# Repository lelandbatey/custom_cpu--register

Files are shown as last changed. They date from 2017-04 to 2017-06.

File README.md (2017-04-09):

CPU Register
============

This repo contains PCB designs for the second component of Ben Eater's
educational 8-bit CPU, the CPU registers. You can [watch Mr. Eaters *fantastic*
series on designing and building this CPU on his Youtube
channel.](https://www.youtube.com/user/eaterbc/videos)

Each CPU will need three of these registers, one to act as the **instruction**
register, one as the **A** register, and one as the **B** register. The
difference between the A/B registers and the instruction register is that the
four most significant bits of the instruction register won't be directed back
onto the bus, but instead are used as input to the instruction decoder. The
design intentionally incorporates fake resistors in between the LED's and the
LS74245 which may be used as the point where those four most significant bits
are split off towards the instruction decoder.

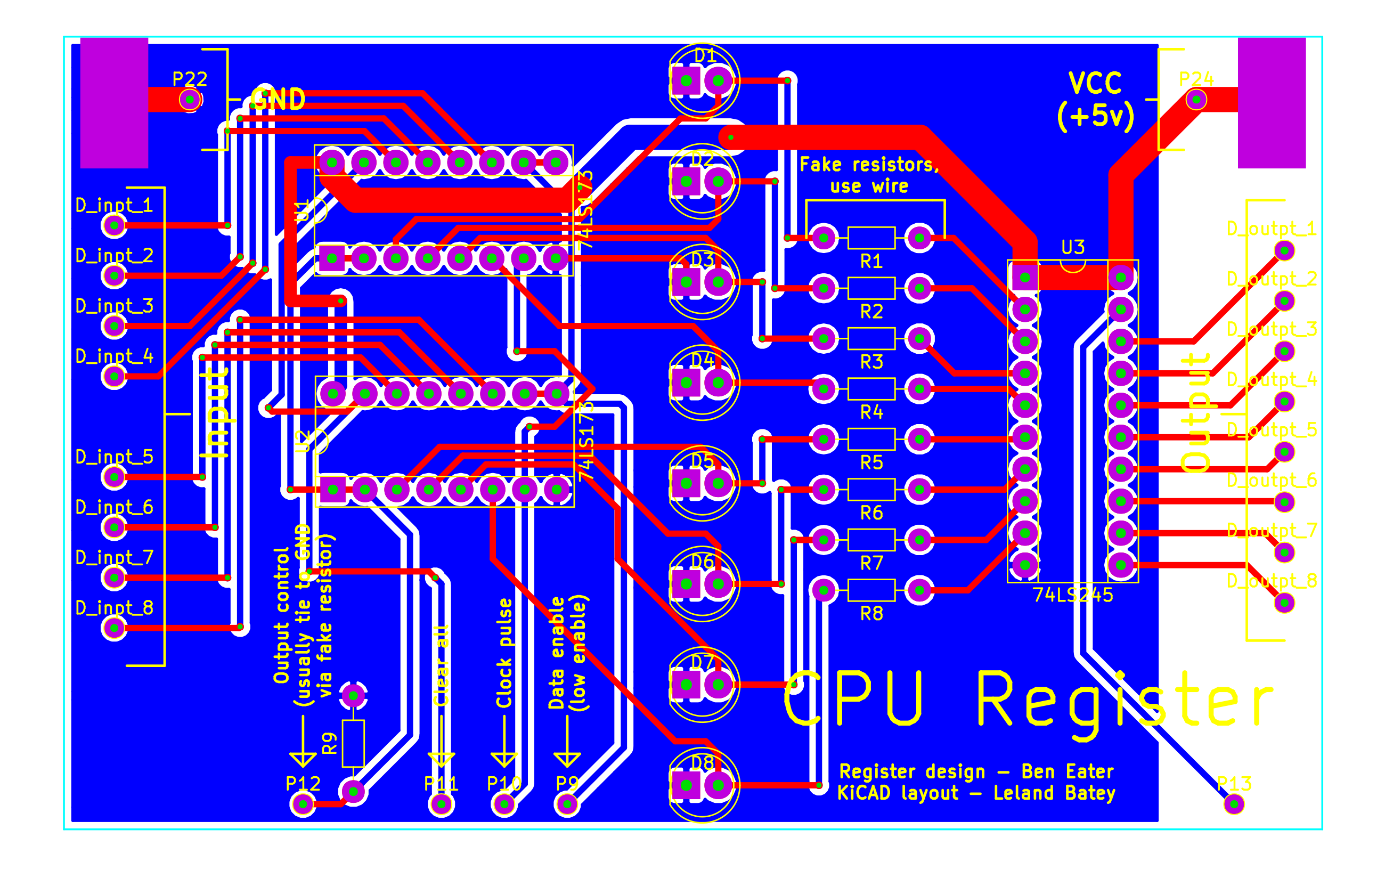
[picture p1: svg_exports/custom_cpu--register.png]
Render of the register PCB


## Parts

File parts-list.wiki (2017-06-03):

= Parts list for register module =

| Part name | Count | Unit Price | Total price |
|---|---|---|---|
| LED (Yellow) | 8 | $0.20 | $1.60 |
| Pin Headers, 1x8 strip | 2 | $0.80 | $1.60 |
| 16 pin IC socket | 2 | $0.18 | $0.36 |
| 20 pin IC socket | 1 | $0.24 | $0.24 |
| 74LS173 (4-bit register) | 2 | $1.35 | $2.70 |
| 74LS245 (bus tranciever) | 1 | $0.87 | $0.87 |
| | | | |

Total:  $7.37

1.6 + 1.6 + 0.36 + 0.24 + 2.7 + 0.87

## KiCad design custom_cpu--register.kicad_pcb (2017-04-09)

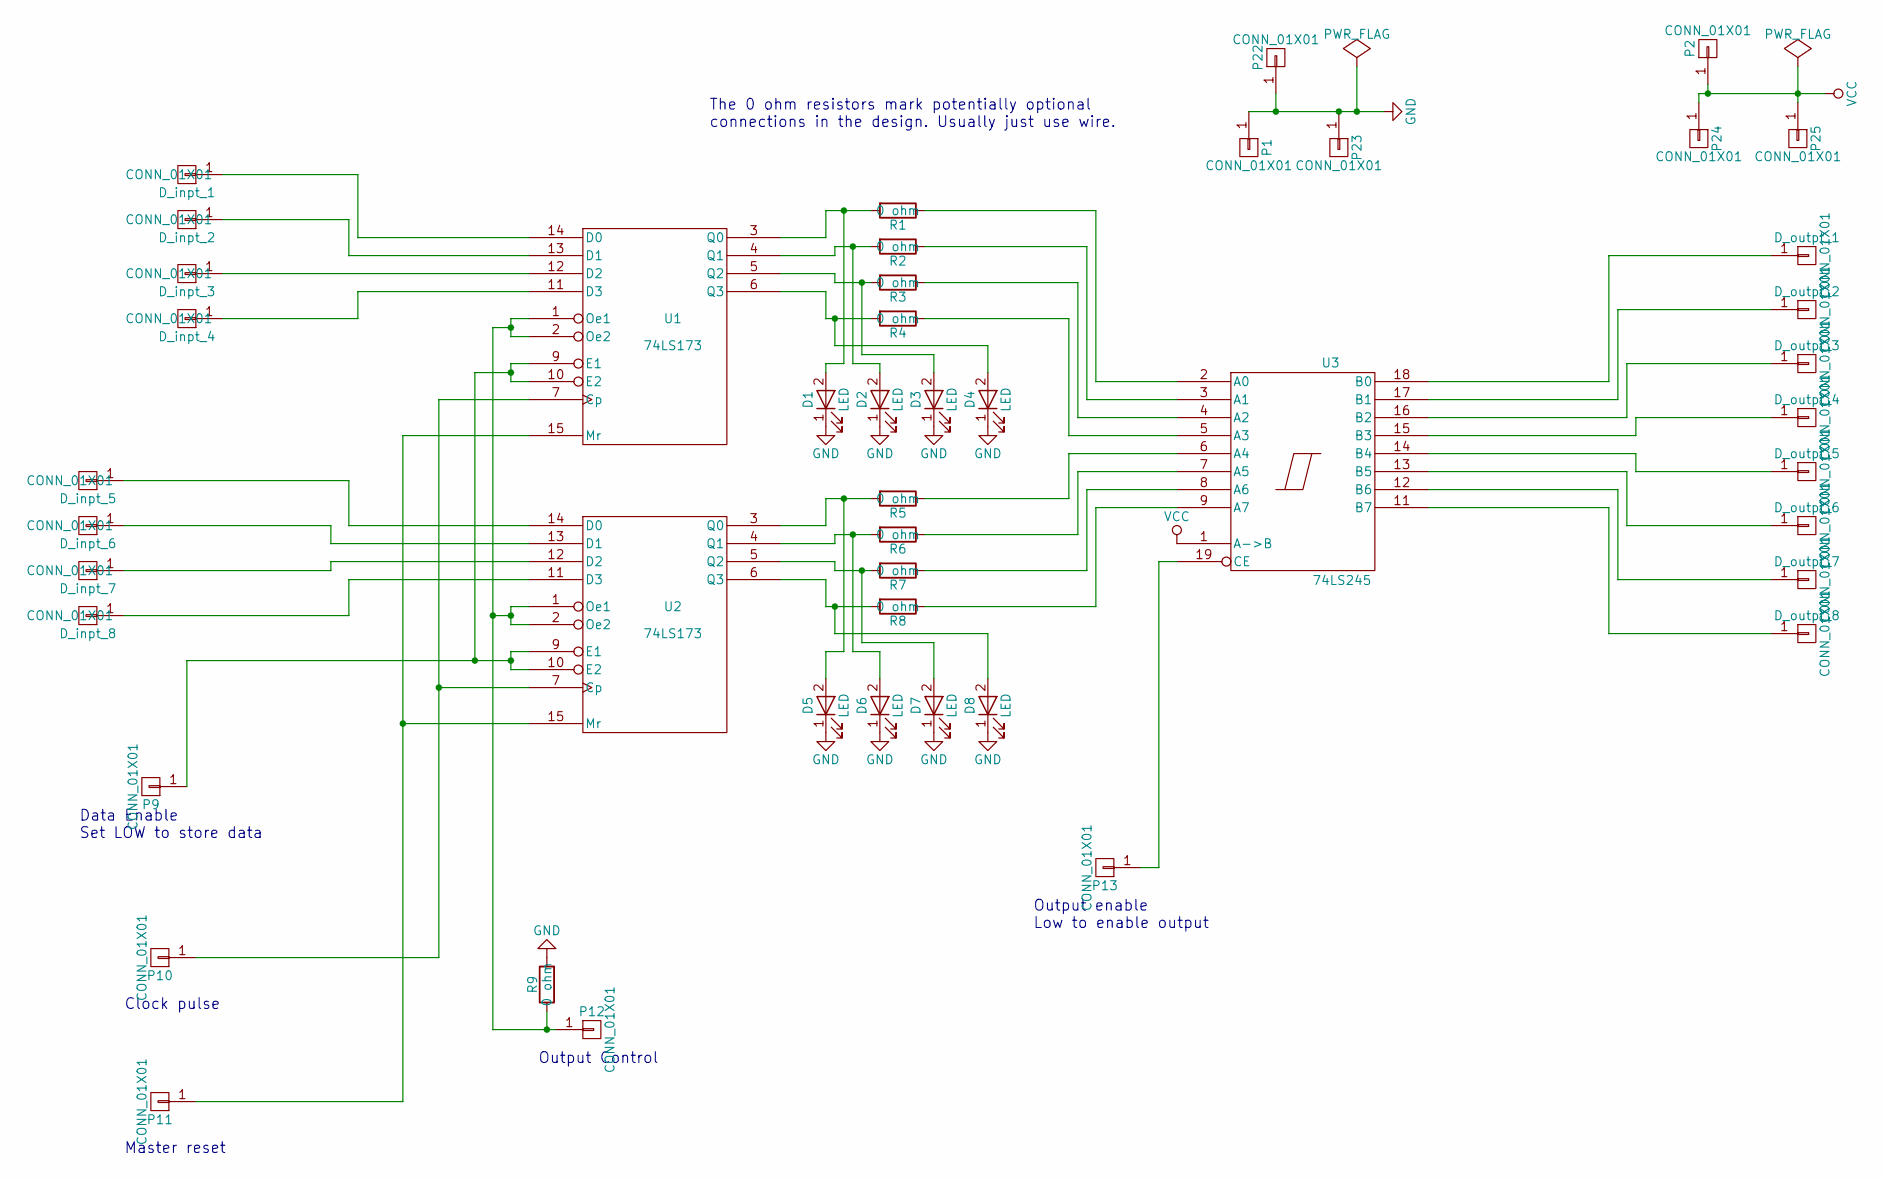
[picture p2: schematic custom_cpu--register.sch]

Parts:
D1, D2, D3, D4, D5, D6, D7, D8: LED; LED_D5.0mm
D_inpt_1, D_inpt_2, D_inpt_3, D_inpt_4, D_inpt_5, D_inpt_6, D_inpt_7, D_inpt_8: CONN_01X01; PINTST
D_outpt_1, D_outpt_2, D_outpt_3, D_outpt_4, D_outpt_5, D_outpt_6, D_outpt_7, D_outpt_8: CONN_01X01; PINTST
P1, P2, P23, P25: CONN_01X01; SolderWirePad_single_SMD_5x10mm
P9, P10, P11, P12, P13, P22, P24: CONN_01X01; PINTST
R1, R2, R3, R4, R5, R6, R7, R8, R9: 0 ohm; R_Axial_DIN0204_L3.6mm_D1.6mm_P7.62mm_Horizontal
U1, U2: 74LS173; DIP-16_W7.62mm_Socket
U3: 74LS245; DIP-20_W7.62mm_Socket

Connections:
GND: D1.1 (K), D2.1 (K), D3.1 (K), D4.1 (K), D5.1 (K), D6.1 (K), D7.1 (K), D8.1 (K), P1.1, P22.1, P23.1, R9.2, U1.8 (GND), U2.8 (GND), U3.10 (GND)
unnamed: D1.2 (A), R1.2, U1.3 (Q0)
unnamed: D2.2 (A), R2.2, U1.4 (Q1)
unnamed: D3.2 (A), R3.2, U1.5 (Q2)
unnamed: D4.2 (A), R4.2, U1.6 (Q3)
unnamed: D5.2 (A), R5.2, U2.3 (Q0)
unnamed: D6.2 (A), R6.2, U2.4 (Q1)
unnamed: D7.2 (A), R7.2, U2.5 (Q2)
unnamed: D8.2 (A), R8.2, U2.6 (Q3)
unnamed: D_inpt_1.1, U1.14 (D0)
unnamed: D_inpt_2.1, U1.13 (D1)
unnamed: D_inpt_3.1, U1.12 (D2)
unnamed: D_inpt_4.1, U1.11 (D3)
unnamed: D_inpt_5.1, U2.14 (D0)
unnamed: D_inpt_6.1, U2.13 (D1)
unnamed: D_inpt_7.1, U2.12 (D2)
unnamed: D_inpt_8.1, U2.11 (D3)
unnamed: D_outpt_1.1, U3.18 (B0)
unnamed: D_outpt_2.1, U3.17 (B1)
unnamed: D_outpt_3.1, U3.16 (B2)
unnamed: D_outpt_4.1, U3.15 (B3)
unnamed: D_outpt_5.1, U3.14 (B4)
unnamed: D_outpt_6.1, U3.13 (B5)
unnamed: D_outpt_7.1, U3.12 (B6)
unnamed: D_outpt_8.1, U3.11 (B7)
unnamed: P9.1, U1.9 (E1), U1.10 (E2), U2.9 (E1), U2.10 (E2)
unnamed: P10.1, U1.7 (Cp), U2.7 (Cp)
unnamed: P11.1, U1.15 (Mr), U2.15 (Mr)
unnamed: P12.1, R9.1, U1.1 (Oe1), U1.2 (Oe2), U2.1 (Oe1), U2.2 (Oe2)
unnamed: P13.1, U3.19 (CE)
unnamed: R1.1, U3.2 (A0)
unnamed: R2.1, U3.3 (A1)
unnamed: R3.1, U3.4 (A2)
unnamed: R4.1, U3.5 (A3)
unnamed: R5.1, U3.6 (A4)
unnamed: R6.1, U3.7 (A5)
unnamed: R7.1, U3.8 (A6)
unnamed: R8.1, U3.9 (A7)
VCC: P2.1, P24.1, P25.1, U1.16 (VCC), U2.16 (VCC), U3.1 (A->B), U3.20 (VCC)

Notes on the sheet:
Data Enable Set LOW to store data
Clock pulse
Master reset
Output Control
Output enable Low to enable output
The 0 ohm resistors mark potentially optional connections in the design. Usually just use wire.

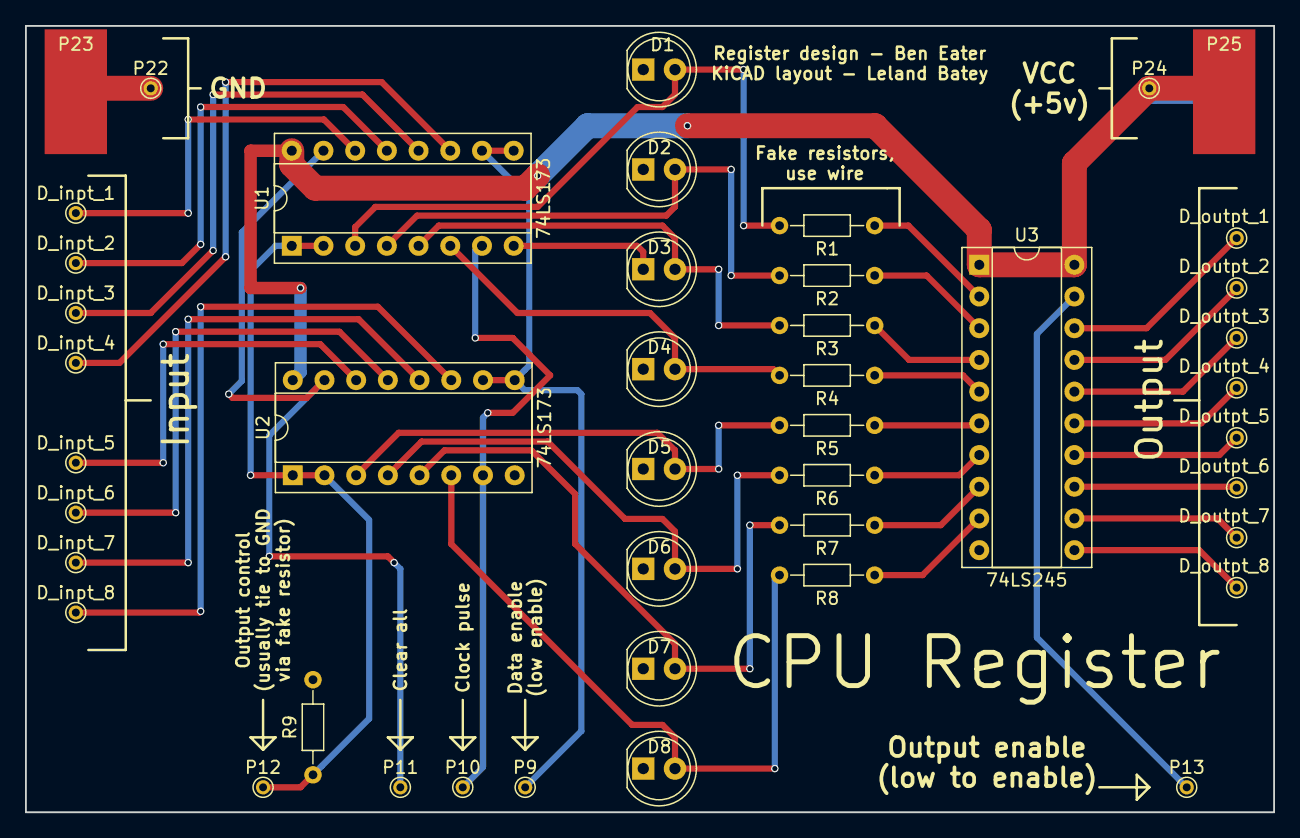
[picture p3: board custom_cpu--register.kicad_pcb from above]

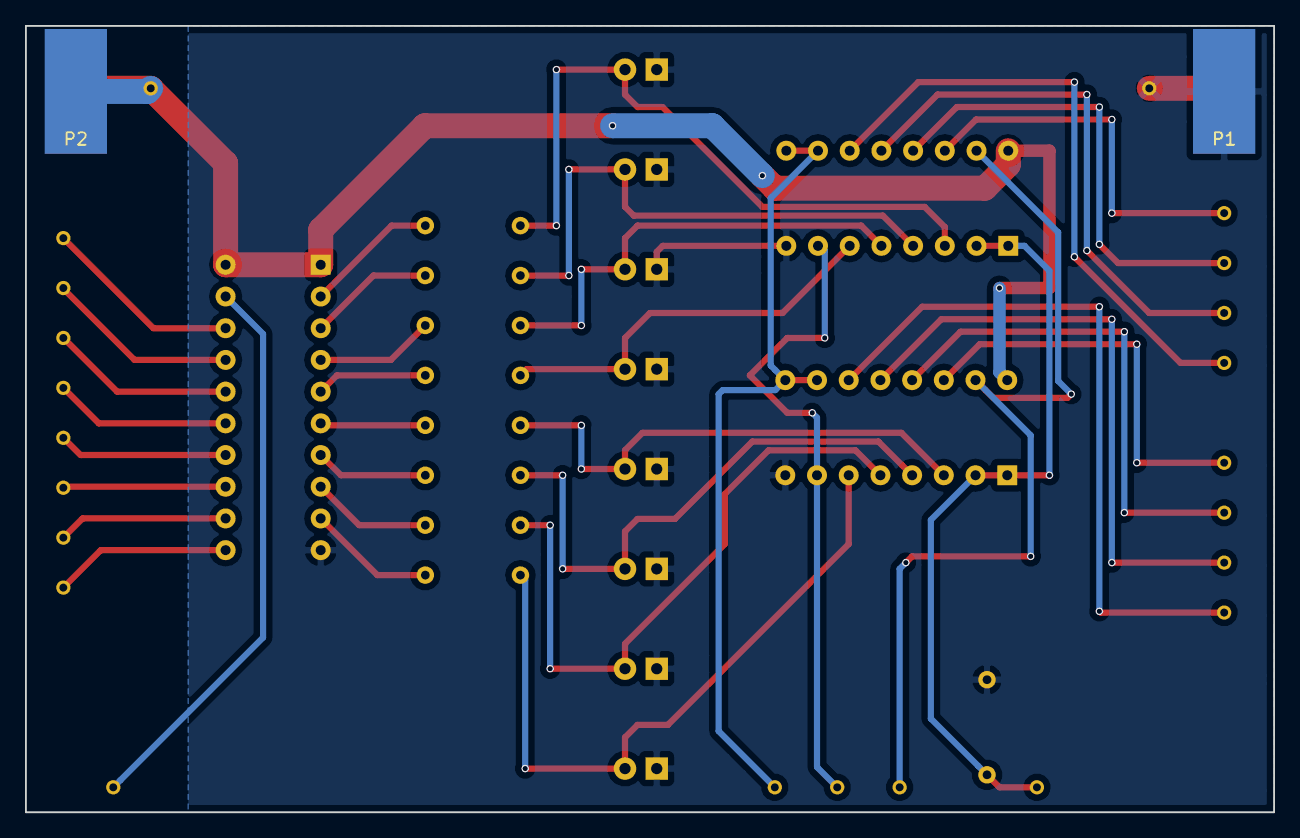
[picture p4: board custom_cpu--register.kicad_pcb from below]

Board: 2 copper layers, 100.0 x 63.0 mm, 47 parts (2 on the bottom side), 39 nets.

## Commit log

2017-04-08 Finish preliminary design
    [custom_cpu--register.kicad_pcb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]
2017-04-09 Tweak trace layout, add PNG version of layout
    [custom_cpu--register.kicad_pcb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]
2017-04-09 Make labels consistent with original design, add README
    [custom_cpu--register.kicad_pcb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]
2017-04-09 Added redundant power pads to back of board
    [custom_cpu--register.kicad_pcb, custom_cpu--register.sch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]
2017-04-09 Add output control label
    [custom_cpu--register.kicad_pcb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]
2017-06-03 Add parts list and cost of materials
